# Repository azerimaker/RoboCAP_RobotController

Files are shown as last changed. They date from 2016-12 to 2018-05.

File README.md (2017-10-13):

# RoboCAP Robot Controller
ATmega328 based Robot Remote Controller and Receiver Circuit. [Read more.](http://makerspace-az.org/az/elektronika/robocap-v-1-0-robot-controller/)

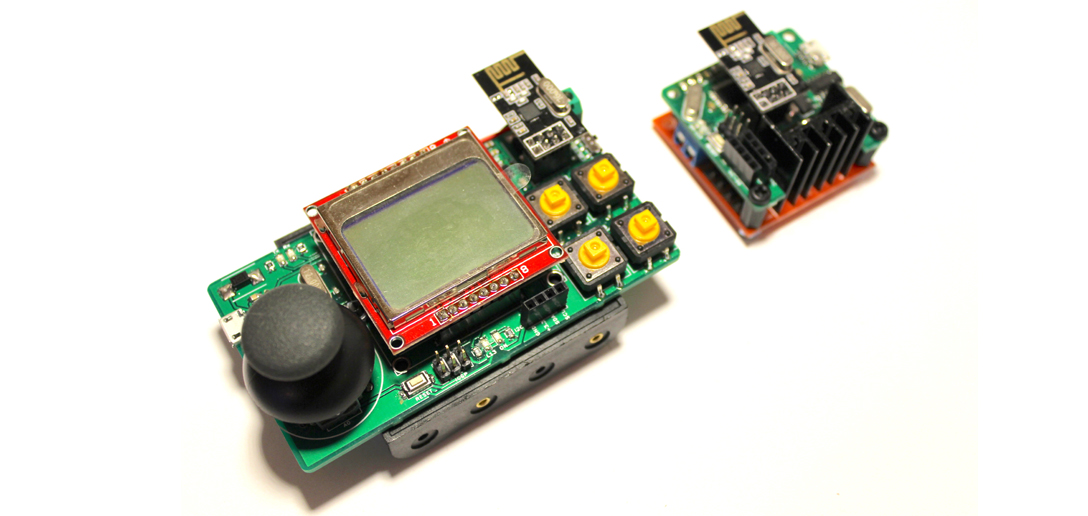
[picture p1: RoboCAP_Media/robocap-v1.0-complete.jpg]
RoboCAP


<div align="center">
<br /> This work is licensed under a <a rel="license" href="http://creativecommons.org/licenses/by-sa/4.0/">Creative Commons Attribution-ShareAlike 4.0 International License</a>.

</div>

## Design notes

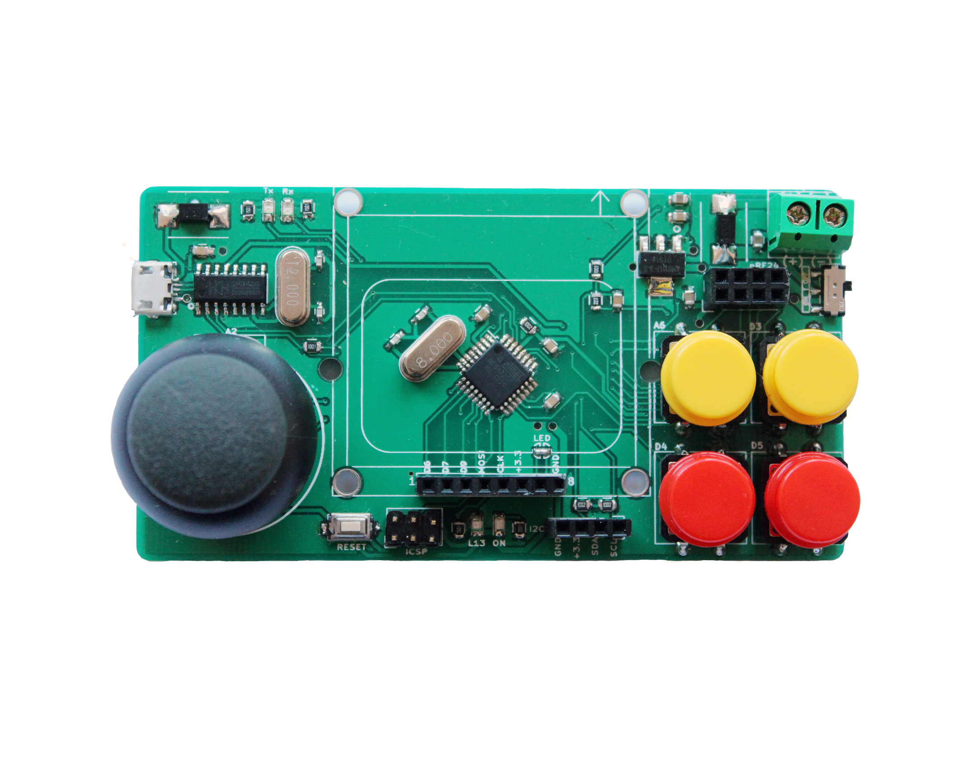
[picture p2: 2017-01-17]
RoboCAP_Media/RoboCAP_Tx.jpg

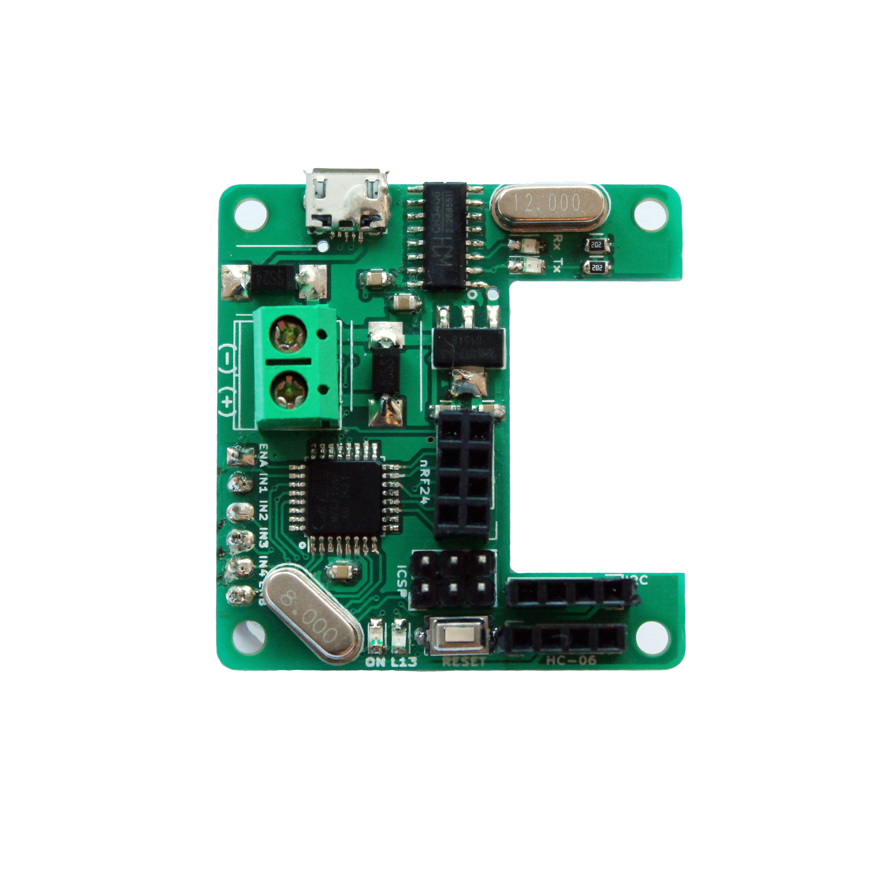
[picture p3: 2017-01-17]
RoboCAP_Media/RoboCAP_Rx.jpg

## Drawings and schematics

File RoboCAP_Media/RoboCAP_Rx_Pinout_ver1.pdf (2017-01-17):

# RoboCAP - Rx ver.1 Pinout

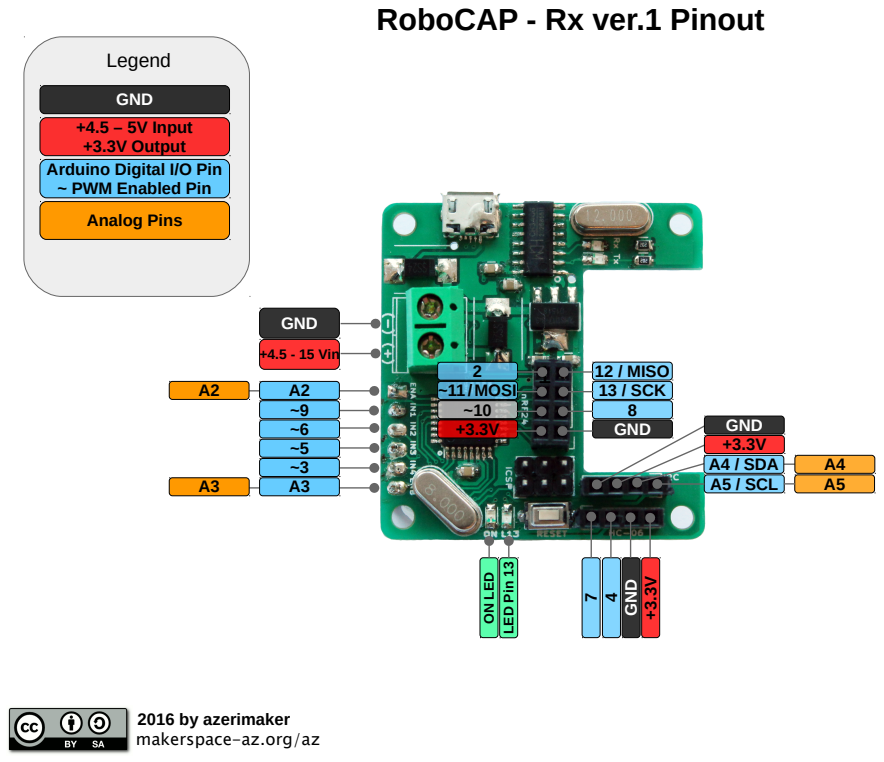
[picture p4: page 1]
~11 /MOSI; 2 12 / MISO; +4.5 - 15 Vin; GND; 8 GND; 13 / SCK; A5 / SCL; A4 / SDA; Legend; Pin

GND
+4.5 – 5V Input
+3.3V Output
Arduino Digital I/O Pin
~ PWM Enabled Pin
Analog Pins

2016 by azerimaker
makerspace-az.org/az

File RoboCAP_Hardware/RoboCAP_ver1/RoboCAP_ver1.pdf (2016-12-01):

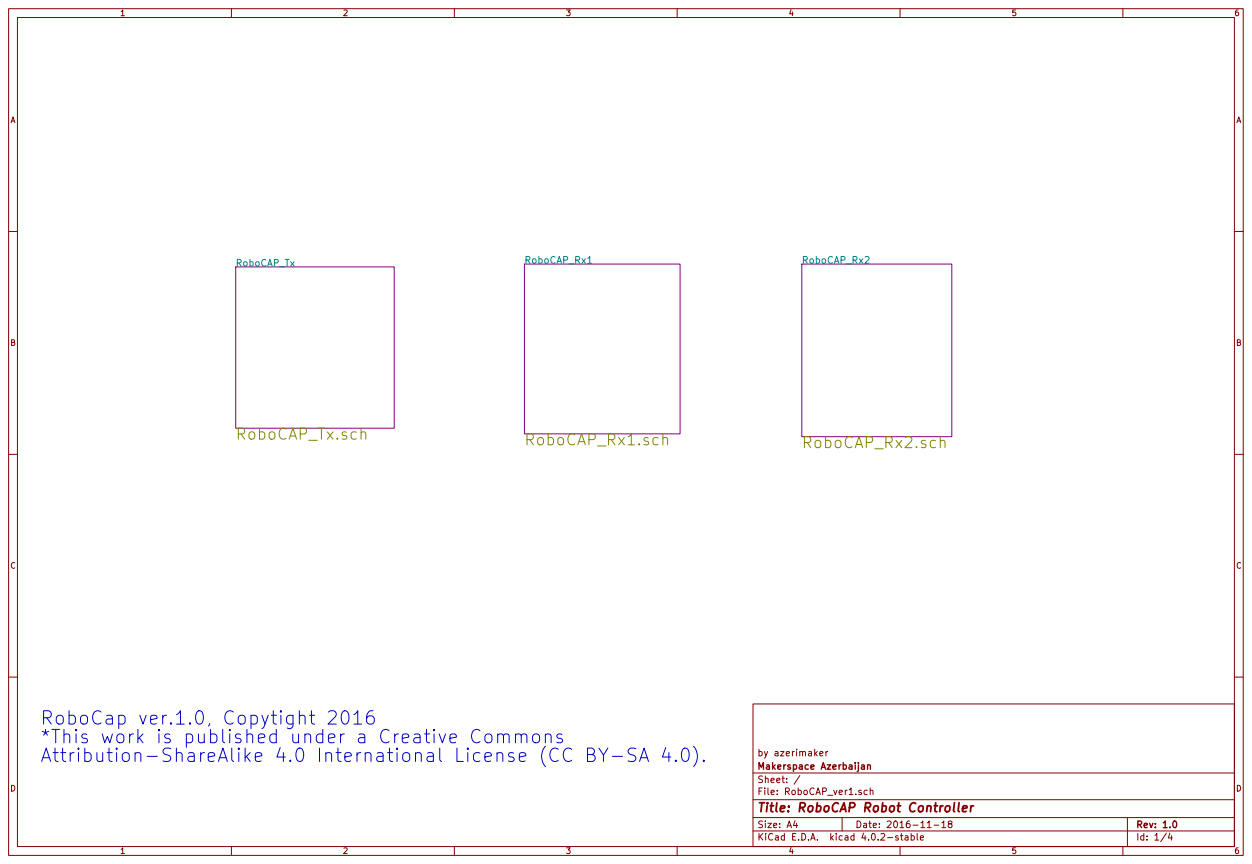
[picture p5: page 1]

RoboCap ver.1.0, Copytight 2016
*This work is published under a Creative Commons
Attribution-ShareAlike 4.0 International License (CC BY-SA 4.0).

by azerimaker
File: RoboCAP_ver1.sch Sheet: / Makerspace Azerbaijan

Id: 1/4 Title: RoboCAP Robot Controller

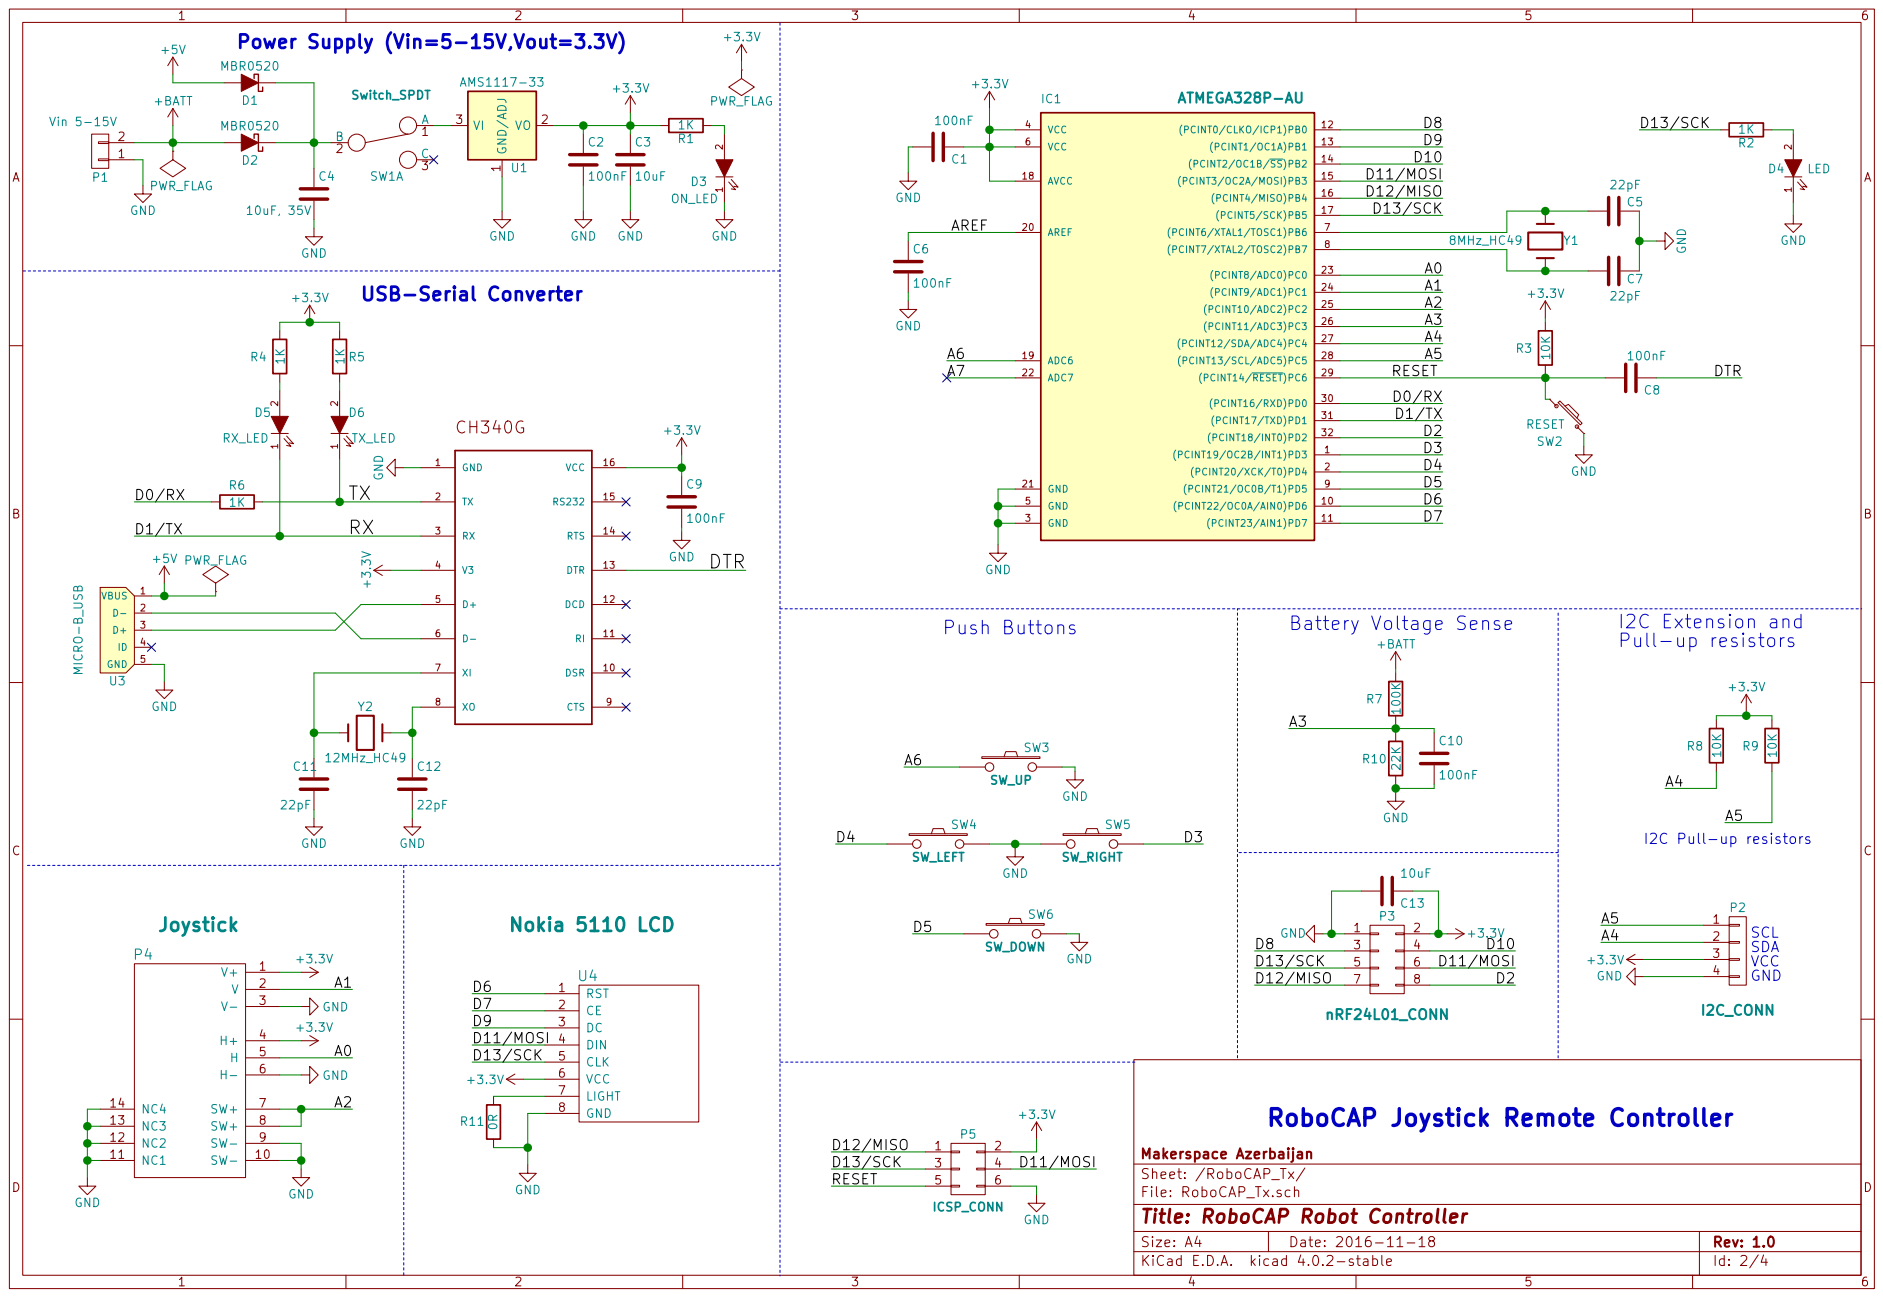
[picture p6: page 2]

RoboCAP Joystick Remote Controller

Makerspace Azerbaijan
Sheet: /RoboCAP_Tx/
File: RoboCAP_Tx.sch
Id: 2/4 Title: RoboCAP Robot Controller

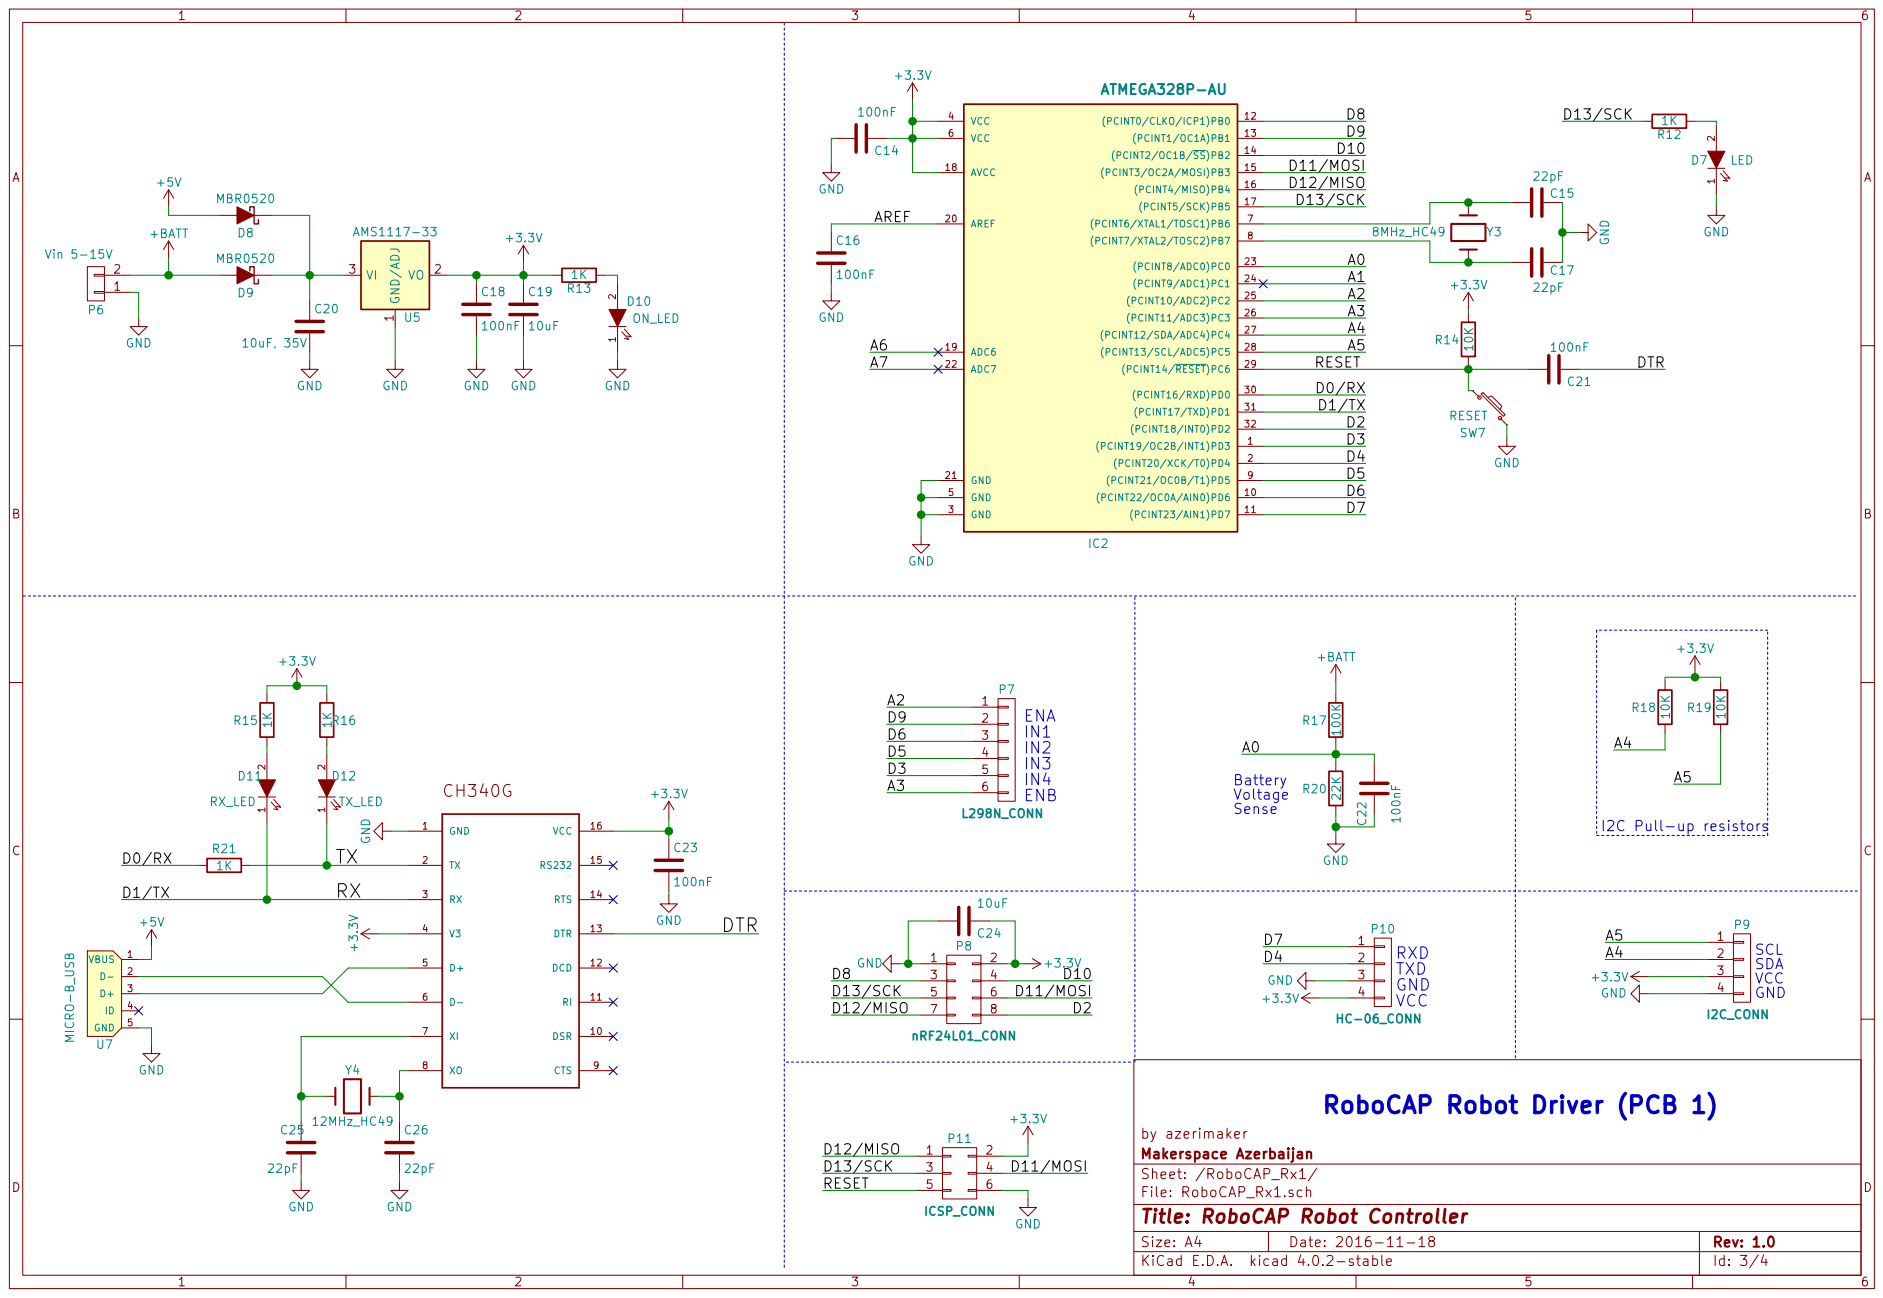
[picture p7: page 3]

RoboCAP Robot Driver (PCB 1)

by azerimaker
Makerspace Azerbaijan
Sheet: /RoboCAP_Rx1/
File: RoboCAP_Rx1.sch
Id: 3/4 Title: RoboCAP Robot Controller

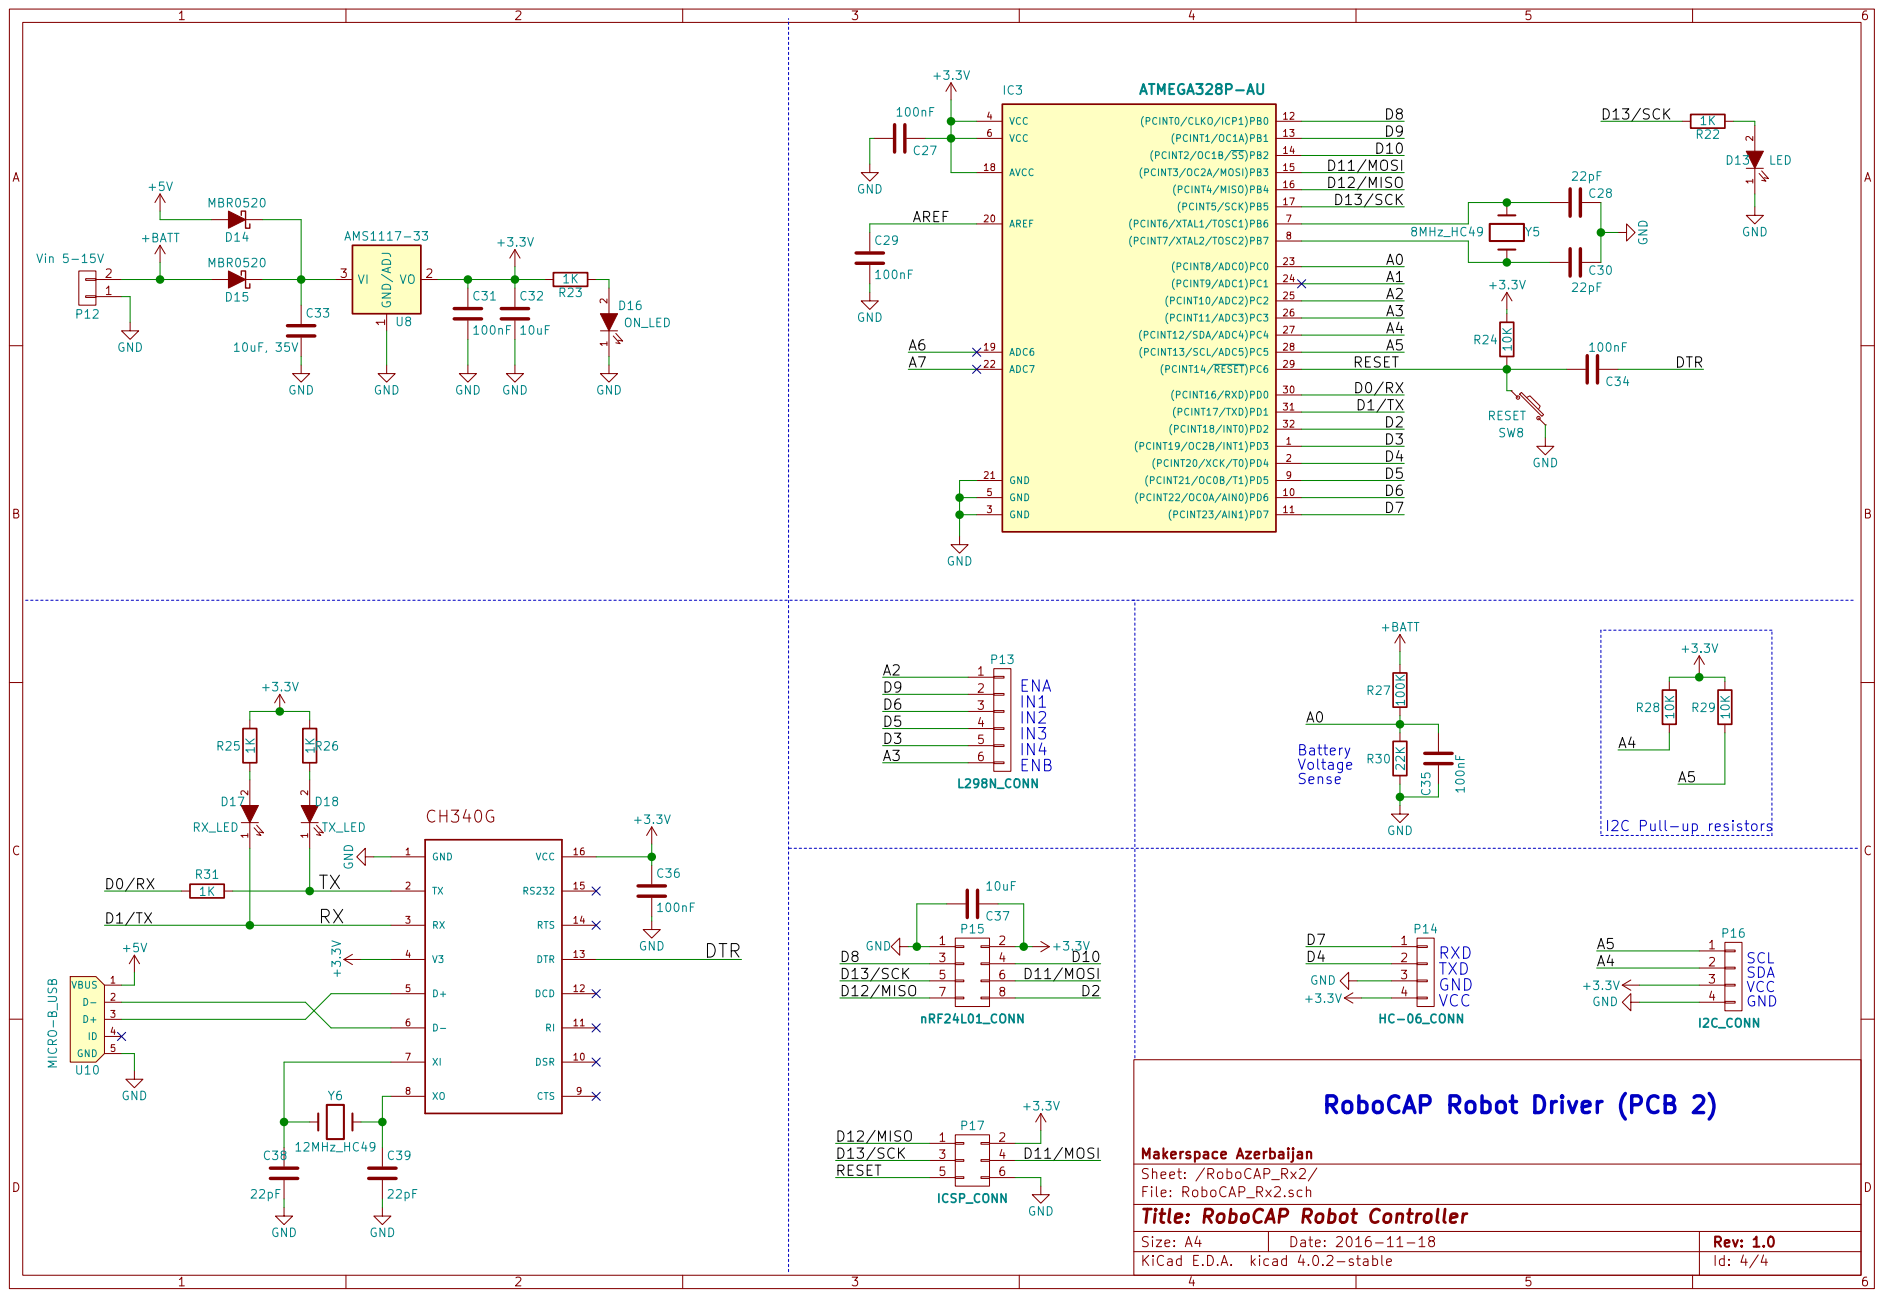
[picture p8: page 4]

RoboCAP Robot Driver (PCB 2)

Makerspace Azerbaijan
Sheet: /RoboCAP_Rx2/
File: RoboCAP_Rx2.sch
Id: 4/4 Title: RoboCAP Robot Controller

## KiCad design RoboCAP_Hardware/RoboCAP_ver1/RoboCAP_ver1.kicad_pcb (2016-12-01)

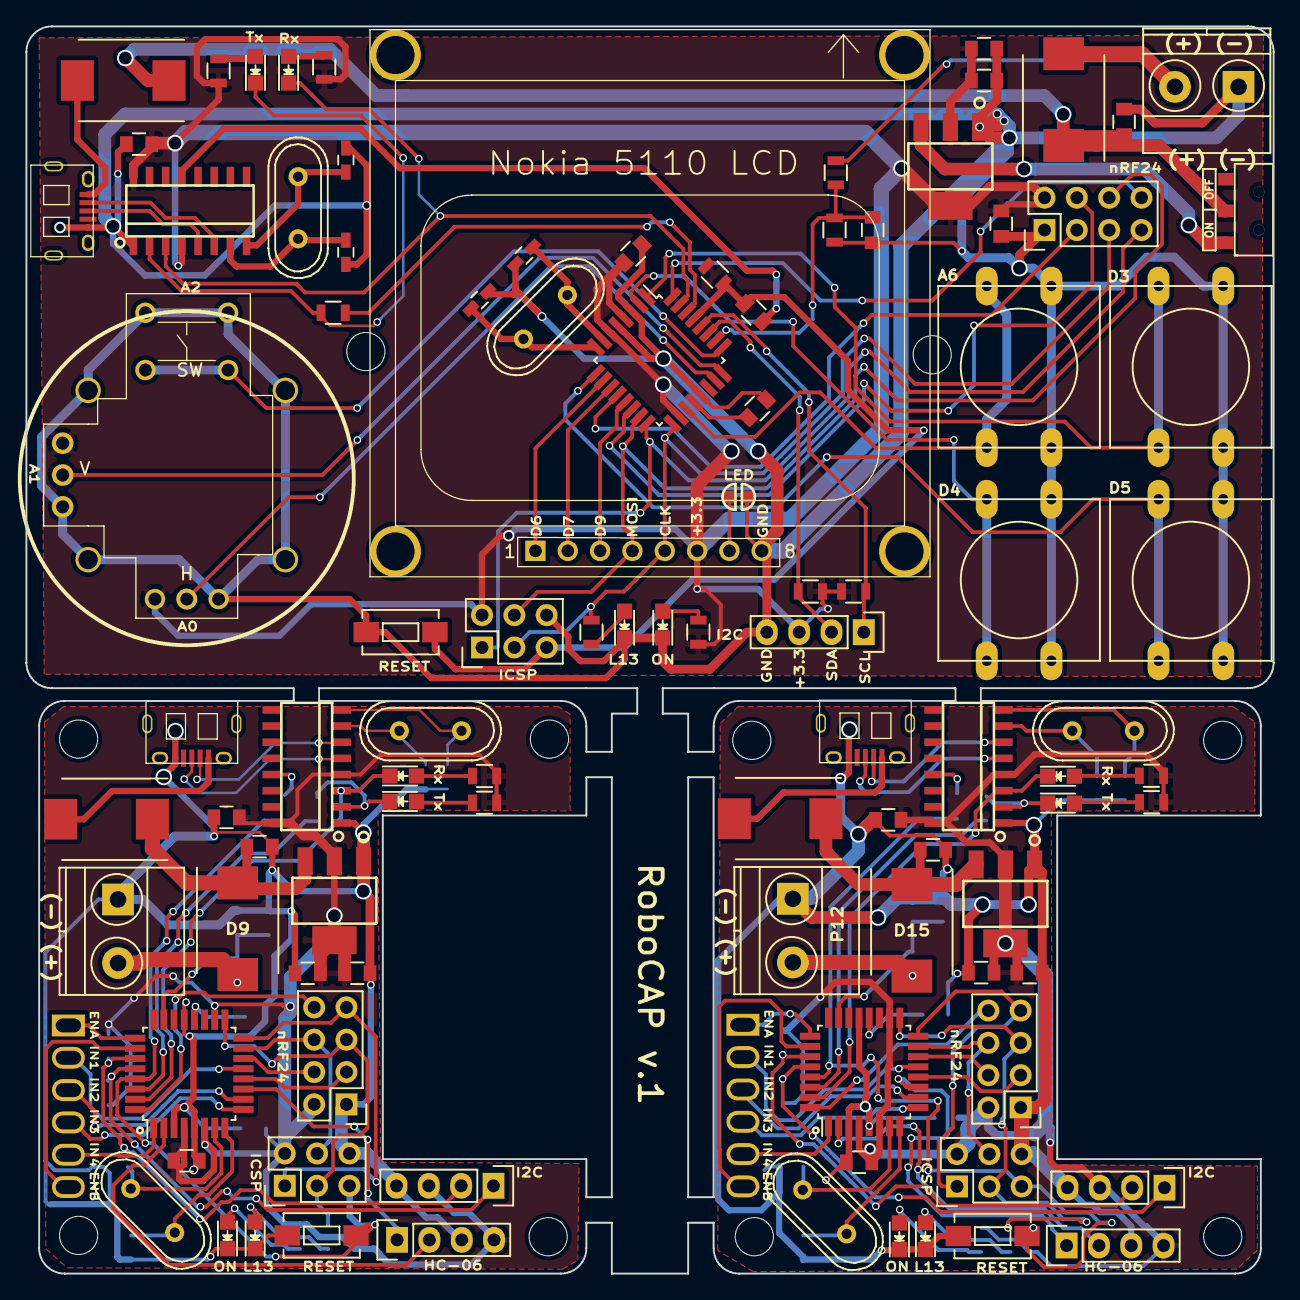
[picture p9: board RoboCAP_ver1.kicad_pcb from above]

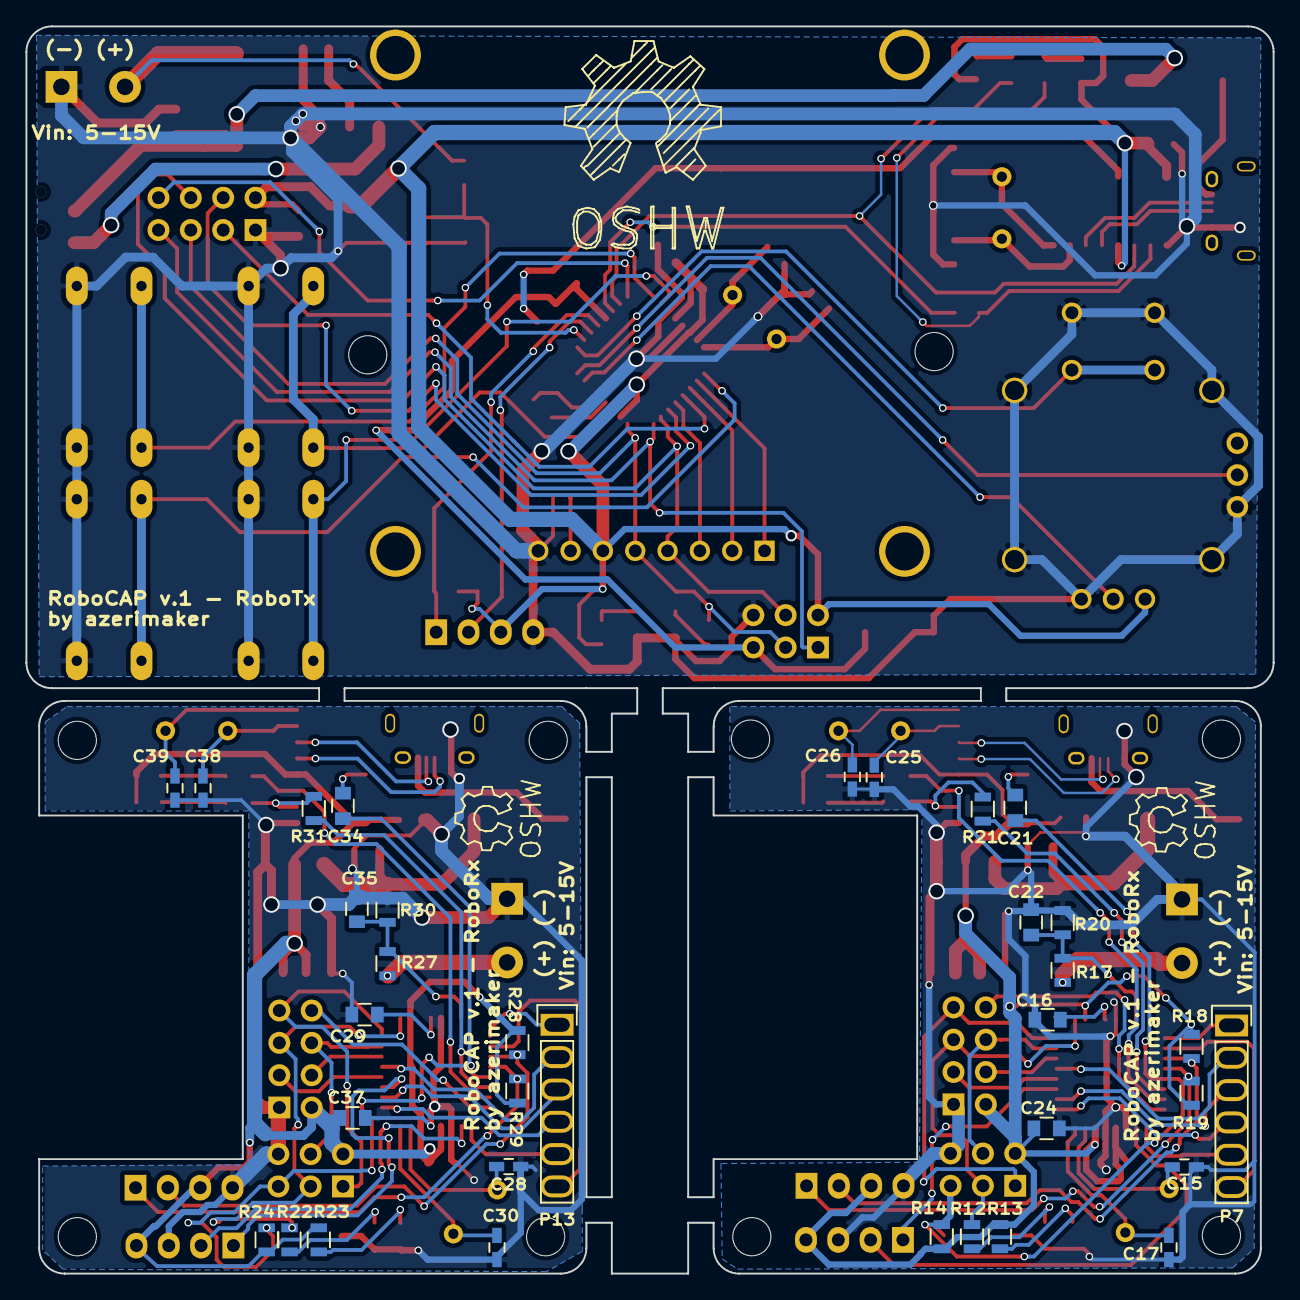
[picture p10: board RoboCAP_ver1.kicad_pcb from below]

Board: 2 copper layers, 98.0 x 98.0 mm, 132 parts (34 on the bottom side), 110 nets.

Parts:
C1, C2, C6, C8, C9, C10, C14, C16, C18, C21, C22, C23, C27, C29, C31, C34, C35, C36: 100nF; C_0805
C3, C13, C19, C24, C32, C37: 10uF; C_0805
C4, C20, C33: 10uF, 35V; C_0805
C5, C7, C11, C12, C15, C17, C25, C26, C28, C30, C38, C39: 22pF; C_0603_HandSoldering
D1, D2, D8, D9, D14, D15: MBR0520; DO-214AB
D3, D10, D16: ON_LED; LED_0805
D4, D7, D13: LED; LED_0805
D5, D11, D17: RX_LED; LED_0805
D6, D12, D18: TX_LED; LED_0805
IC1, IC2, IC3: ATMEGA328P-AU; TQFP-32_7x7mm_Pitch0.8mm
P1, P6, P12: Vin 5-15V; TerminalBlock_Pheonix_MKDS1.5-2pol
P2, P9, P16: I2C_CONN; Pin_Header_Straight_1x04
P3, P8, P15: nRF24L01_CONN; Pin_Header_Straight_2x04
P4: Joystick
P5, P11, P17: ICSP_CONN; Pin_Header_Straight_2x03
P7, P13: L298N_CONN; Pin_Header_Straight_1x06
P10, P14: HC-06_CONN; Pin_Header_Straight_1x04
R1, R2, R4, R5, R6, R12, R13, R15, R16, R21, R22, R23, R25, R26, R31: 1K; R_0805
R3, R8, R9, R14, R18, R19, R24, R28, R29: 10K; R_0805
R7, R17, R27: 100K; R_0805
R10: 33K; R_0805
R11: 0R; SOLDER-JUMPER_1-WAY
R20, R30: 22K; R_0805
SW1: Switch_SPDT; AYZ0102AGRLC
SW2, SW7, SW8: RESET; SW_SPST_EVQPE1
SW3: SW_UP; SW_PUSH-12mm
SW4: SW_LEFT; SW_PUSH-12mm
SW5: SW_RIGHT; SW_PUSH-12mm
SW6: SW_DOWN; SW_PUSH-12mm
U1, U5, U8: AMS1117-33; SOT223
U2, U6, U9: CH340G; SOIC16
U3, U7, U10: MICRO-B_USB; Micro_USB_TH
U4: Nokia 5110 LCD; Nokia_5110_LCD
Y1, Y3, Y5: 8MHz_HC49; Crystal_HC49-U_Vertical
Y2, Y4, Y6: 12MHz_HC49; Crystal_HC49-U_Vertical

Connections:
+3V3: C1.1, C2.1, C3.1, C9.1, C13.1, C14.1, C18.1, C19.1, C23.1, C24.1, C27.1, C31.1, C32.1, C36.1, C37.1, IC1.4, IC1.6, IC1.18, IC2.4, IC2.6, IC2.18, IC3.4, IC3.6, IC3.18, P2.3, P3.2, P4.1, P4.4, P5.2, P8.2, P9.3, P10.4, P11.2, P14.4, P15.2, P16.3, P17.2, R1.2, R3.2, R4.2, R5.2, R8.2, R9.2, R13.2, R14.2, R15.2, R16.2, R18.2, R19.2, R23.2, R24.2, R25.2, R26.2, R28.2, R29.2, U1.2, U1.4, U2.4, U2.16, U4.6, U5.2, U5.4, U6.4, U6.16, U8.2, U8.4, U9.4, U9.16
+5V: D1.2, D8.2, D14.2, U3.1, U7.1, U10.1
+BATT: D2.2, D9.2, D15.2, P1.2, P6.2, P12.2, R7.2, R17.2, R27.2
/RoboCAP_Rx1/A0: C22.2, IC2.23, R17.1, R20.2
/RoboCAP_Rx1/A2: IC2.25, P7.1
/RoboCAP_Rx1/A3: IC2.26, P7.6
/RoboCAP_Rx1/A4: IC2.27, P9.2, R18.1
/RoboCAP_Rx1/A5: IC2.28, P9.1, R19.1
/RoboCAP_Rx1/AREF: C16.1, IC2.20
/RoboCAP_Rx1/D0/RX: IC2.30, R21.1
/RoboCAP_Rx1/D1/TX: D11.1, IC2.31, U6.3
/RoboCAP_Rx1/D2: IC2.32, P8.8
/RoboCAP_Rx1/D3: IC2.1, P7.5
/RoboCAP_Rx1/D4: IC2.2, P10.2
/RoboCAP_Rx1/D5: IC2.9, P7.4
/RoboCAP_Rx1/D6: IC2.10, P7.3
/RoboCAP_Rx1/D7: IC2.11, P10.1
/RoboCAP_Rx1/D8: IC2.12, P8.3
/RoboCAP_Rx1/D9: IC2.13, P7.2
/RoboCAP_Rx1/D10: IC2.14, P8.4
/RoboCAP_Rx1/D11/MOSI: IC2.15, P8.6, P11.4
/RoboCAP_Rx1/D12/MISO: IC2.16, P8.7, P11.1
/RoboCAP_Rx1/D13/SCK: IC2.17, P8.5, P11.3, R12.2
/RoboCAP_Rx1/DTR: C21.1, U6.13
/RoboCAP_Rx1/RESET: C21.2, IC2.29, P11.5, R14.1, SW7.1
/RoboCAP_Rx1/TX: D12.1, R21.2, U6.2
/RoboCAP_Rx2/A0: C35.2, IC3.23, R27.1, R30.2
/RoboCAP_Rx2/A2: IC3.25, P13.1
/RoboCAP_Rx2/A3: IC3.26, P13.6
/RoboCAP_Rx2/A4: IC3.27, P16.2, R28.1
/RoboCAP_Rx2/A5: IC3.28, P16.1, R29.1
/RoboCAP_Rx2/AREF: C29.1, IC3.20
/RoboCAP_Rx2/D0/RX: IC3.30, R31.1
/RoboCAP_Rx2/D1/TX: D17.1, IC3.31, U9.3
/RoboCAP_Rx2/D2: IC3.32, P15.8
/RoboCAP_Rx2/D3: IC3.1, P13.5
/RoboCAP_Rx2/D4: IC3.2, P14.2
/RoboCAP_Rx2/D5: IC3.9, P13.4
/RoboCAP_Rx2/D6: IC3.10, P13.3
/RoboCAP_Rx2/D7: IC3.11, P14.1
/RoboCAP_Rx2/D8: IC3.12, P15.3
/RoboCAP_Rx2/D9: IC3.13, P13.2
/RoboCAP_Rx2/D10: IC3.14, P15.4
/RoboCAP_Rx2/D11/MOSI: IC3.15, P15.6, P17.4
/RoboCAP_Rx2/D12/MISO: IC3.16, P15.7, P17.1
/RoboCAP_Rx2/D13/SCK: IC3.17, P15.5, P17.3, R22.2
/RoboCAP_Rx2/DTR: C34.1, U9.13
/RoboCAP_Rx2/RESET: C34.2, IC3.29, P17.5, R24.1, SW8.1
/RoboCAP_Rx2/TX: D18.1, R31.2, U9.2
/RoboCAP_Tx/A0: IC1.23, P4.5
/RoboCAP_Tx/A1: IC1.24, P4.2
/RoboCAP_Tx/A2: IC1.25, P4.7, P4.8
/RoboCAP_Tx/A3: C10.1, IC1.26, R7.1, R10.2
/RoboCAP_Tx/A4: IC1.27, P2.2, R8.1
/RoboCAP_Tx/A5: IC1.28, P2.1, R9.1
/RoboCAP_Tx/A6: IC1.19, SW3.1
/RoboCAP_Tx/AREF: C6.1, IC1.20
/RoboCAP_Tx/D0/RX: IC1.30, R6.1
/RoboCAP_Tx/D1/TX: D5.1, IC1.31, U2.3
/RoboCAP_Tx/D2: IC1.32, P3.8
/RoboCAP_Tx/D3: IC1.1, SW5.2
/RoboCAP_Tx/D4: IC1.2, SW4.1
/RoboCAP_Tx/D5: IC1.9, SW6.1
/RoboCAP_Tx/D6: IC1.10, U4.1
/RoboCAP_Tx/D7: IC1.11, U4.2
/RoboCAP_Tx/D8: IC1.12, P3.3
/RoboCAP_Tx/D9: IC1.13, U4.3
/RoboCAP_Tx/D10: IC1.14, P3.4
/RoboCAP_Tx/D11/MOSI: IC1.15, P3.6, P5.4, U4.4
/RoboCAP_Tx/D12/MISO: IC1.16, P3.7, P5.1
/RoboCAP_Tx/D13/SCK: IC1.17, P3.5, P5.3, R2.2, U4.5
/RoboCAP_Tx/DTR: C8.1, U2.13
/RoboCAP_Tx/RESET: C8.2, IC1.29, P5.5, R3.1, SW2.1
/RoboCAP_Tx/TX: D6.1, R6.2, U2.2
GND: C1.2, C2.2, C3.2, C4.2, C5.1, C6.2, C7.1, C9.2, C10.2, C11.2, C12.2, C13.2, C14.2, C15.1, C16.2, C17.1, C18.2, C19.2, C20.2, C22.1, C23.2, C24.2, C25.2, C26.2, C27.2, C28.1, C29.2, C30.1, C31.2, C32.2, C33.2, C35.1, C36.2, C37.2, C38.2, C39.2, D3.1, D4.1, D7.1, D10.1, D13.1, D16.1, IC1.3, IC1.5, IC1.21, IC2.3, IC2.5, IC2.21, IC3.3, IC3.5, IC3.21, P1.1, P2.4, P3.1, P4.3, P4.6, P4.9, P4.10, P4.11, P4.12, P4.13, P4.14, P5.6, P6.1, P8.1, P9.4, P10.3, P11.6, P12.1, P14.3, P15.1, P16.4, P17.6, R10.1, R11.2, R20.1, R30.1, SW2.2, SW3.2, SW4.2, SW5.1, SW6.2, SW7.2, SW8.2, U1.1, U2.1, U3.5, U4.8, U5.1, U6.1, U7.5, U8.1, U9.1, U10.5
unnamed: C4.1, D1.1, D2.1, SW1.2
unnamed: C5.2, IC1.7, Y1.1
unnamed: C7.2, IC1.8, Y1.2
unnamed: C11.1, U2.7, Y2.1
unnamed: C12.1, U2.8, Y2.2
unnamed: C15.2, IC2.7, Y3.1
unnamed: C17.2, IC2.8, Y3.2
unnamed: C20.1, D8.1, D9.1, U5.3
unnamed: C25.1, U6.7, Y4.1
unnamed: C26.1, U6.8, Y4.2
unnamed: C28.2, IC3.7, Y5.1
unnamed: C30.2, IC3.8, Y5.2
unnamed: C33.1, D14.1, D15.1, U8.3
unnamed: C38.1, U9.7, Y6.1
unnamed: C39.1, U9.8, Y6.2
unnamed: D3.2, R1.1
unnamed: D4.2, R2.1
unnamed: D5.2, R4.1
unnamed: D6.2, R5.1
unnamed: D7.2, R12.1
unnamed: D10.2, R13.1
unnamed: D11.2, R15.1
unnamed: D12.2, R16.1
unnamed: D13.2, R22.1
unnamed: D16.2, R23.1
unnamed: D17.2, R25.1
unnamed: D18.2, R26.1
unnamed: R11.1, U4.7
unnamed: SW1.1, U1.3
unnamed: U2.5, U3.3
unnamed: U2.6, U3.2
unnamed: U6.5, U7.3
unnamed: U6.6, U7.2
unnamed: U9.6, U10.2
unnamed: U9.5, U10.3

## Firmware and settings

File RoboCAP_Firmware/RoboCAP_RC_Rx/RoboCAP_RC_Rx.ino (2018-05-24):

/*
 * www.Makerspace-Az.org
 * Arduino Sketch: 4X4 Robot masin, Radio Receiver Robot Control (Rx)
 * Kommunikasiya: nRF24L01 2.4GHz
 * son modifikasia tarixi: 21 Iyul 2016
 * [azerimaker]
*/

/*-----( Kitabxana elavesi)-----*/
#include <SPI.h>
#include <RF24.h>
//#include <SoftwareSerial.h>


// eyni anda yalniz bir rejimi aktivlesdirin
//#define BLUETOOTH_MODE
//#define nRF_MODE


/*-----(  Sabitler ve Pin Nomreleri )-----*/
#define MAX_SPEED 255 // analogWrite maks qiymeti

// nRF24L01 modulu uchun
#define CE_PIN   8  
#define CSN_PIN 10

// L298n Motor Surucu pinleri
#define ENA A2      // Motor A Enable 
#define motor1A 9     // INA 
#define motor1B 6     // INB
#define motor2A 5     // INC
#define motor2B 3     // IND
#define ENB A3		  // Motor B Enable

#define VBAT A0      // Batareya gerginliyi
#define V_Divider_Coeff 0.01801F // gerginlik bolucuden alinir

// HC-06 Bluetooth Modul pinleri
//#define Rx 4          // -> HC-06 TxD    
//#define Tx 7 		  // -> HC-06 RxD

#define X_min 480
#define X_max 530
#define Y_min 480
#define Y_max 530

 // deyishenlar ve sabitler
//char BT_RECEIVED;   // BT-dan gelen simvol
//char PC_RECEIVED;   // PC-den gelen simvol

/*-----( Radio Obyektinin yaradilmasi )-----*/
RF24 radio(CE_PIN, CSN_PIN);
// Hardware serial PC ile kommunikasiya ucun lazim oldughu ucun SoftwareSerial ishledirik
//SoftwareSerial BTserial(Rx, Tx);

/*-----( Funksiya Prototipleri )-----*/
void calcDirection(int X_pos, int Y_pos);
void calcSpeed(int X_pos, int Y_pos);
void driveRobot(char DIRECTION, unsigned char SPEED);
void setSpeedRight(unsigned char SPEED, boolean DIR);
void setSpeedLeft(unsigned char SPEED, boolean DIR);
void motorTormozla(void);
int  readBatteryVoltage(void);

/*-----( Deyishenler )-----*/
byte addresses[][6] = {"1Node", "2Node"}; //  nRF ucun "Pipe" adlari
byte failsafe_count = 0; 

struct dataStruct {
  unsigned long micro_sec;  // to save response times
  int Xposition;          // The Joystick position values
  int Yposition;
  bool switchOn;          // The Joystick push-down switch
  bool TL_BTN; 
  bool TR_BTN;
  bool BL_BTN;
  bool BR_BTN;
  int robot_Vbat;
} myData;  

char Joystick_Dir;     // Joystick kordinatlarini hereket istiqametine ve 
unsigned char Joystick_Speed = 0;   // surete cevirmek
int X_map, Y_map;
unsigned int X_sq, Y_sq;     // suret vektorunun hesablamaq uchun

boolean FORWARD = true; // ireli
boolean BACKWARD = false; // geri

/****** SETUP: Bir defe icra olunacaq ******/                       
void setup() 
{
  Serial.begin(9600);
  
  pinMode(motor1A, OUTPUT);
  pinMode(motor1B, OUTPUT);
  pinMode(motor2A, OUTPUT);
  pinMode(motor2B, OUTPUT);
  pinMode(ENA, OUTPUT);
  pinMode(ENB, OUTPUT);
  
  // L298n aktivlesdir 
  digitalWrite(ENA, HIGH);
  digitalWrite(ENB, HIGH);
  motorTormozla(); // tekerleri tormozla, ehtiyat ucun
  
  //BTserial.begin(9600);
  radio.begin();  
  radio.setChannel(108);  //   2.508 Ghz - WiFi siqnallarindan yuksek bir kanal deyeri sech
  radio.setDataRate(RF24_250KBPS); // Data gonderme sureti
  radio.setPALevel(RF24_PA_LOW); // Oturme gucu: RF24_PA_MIN, RF24_PA_LOW, RF24_PA_HIGH, RF24_PA_MAX

  radio.openWritingPipe(addresses[1]); // Oturucu Pipe (kanali) ishe sal
  radio.openReadingPipe(1, addresses[0]); // Qebul Pipe (kanali) ishe sal
  
  radio.startListening(); // Radio siqnallari dinlemeye bashla
  //radio.printDetails(); //kommenti sileniz coxlu Debug informasiyasi print olunacaq

} /****** SETUP sonu ******/


// implement MODE selection

 /****** LOOP: Daimi tekrarlanir ******/
void loop()
{ 
    if ( radio.available() )
    {		
      while ( radio.available() )   // Qebul Pipe-da melumat olarsa
      {
        radio.read( &myData, sizeof(myData) ); // Radio melumati oxu
      }
      
      radio.stopListening();  
        myData.robot_Vbat =  readBatteryVoltage();           // Batareya gerginliyini elave et                        // First, stop listening so we can transmit
        radio.write( &myData, sizeof(myData) );              // Send the received data back.
      radio.startListening();                              // Now, resume listening so we catch the next packets.
      

      // Yeni qebul olunmush melumati robotun hereket sxemine uyghunlashdir
      calcDirection(myData.Xposition, myData.Yposition); // S,F,B,L,R,I,G,H,J
      calcSpeed(myData.Xposition, myData.Yposition);  // 0-255
      driveRobot(Joystick_Dir, Joystick_Speed);

      Serial.print("X:"); Serial.print(myData.Xposition);
      Serial.print(" Y:"); Serial.print(myData.Yposition);
      Serial.print(" SW:"); Serial.print(myData.switchOn);
      Serial.print(" A6:"); Serial.print(myData.TL_BTN); 
      Serial.print(" D3:"); Serial.print(myData.TR_BTN);
      Serial.print(" D4:"); Serial.print(myData.BL_BTN);
      Serial.print(" D5:"); Serial.print(myData.BR_BTN);
      Serial.print(" vBat:"); Serial.print(myData.robot_Vbat);
      Serial.print(" Dir:"); Serial.print(Joystick_Dir);
      Serial.print(" Speed:"); Serial.println(Joystick_Speed);

    }else{
      failsafe_count++; 
      if(failsafe_count>10){
        failsafe_count=0;
        motorTormozla();
      }
    }
    delay(20);

}  /****** LOOP sonu ******/

 /*
 * Bu funksiya X,Y qiymetlerine esasen qlobal 
 * Istiqamet deyishenini yenileyir 
 */ 

 void calcDirection(int X_pos, int Y_pos){
  
  if((X_pos >= X_min && X_pos <= X_max) && Y_pos >= Y_max)
  {
    Joystick_Dir = 'F';
  }
  else if(X_pos >= X_min && X_pos <= X_max && Y_pos <= Y_min)
  {
    Joystick_Dir = 'B';
  }
  else if(Y_pos >= Y_min && Y_pos <= Y_max && X_pos >= X_max)
  {
    Joystick_Dir = 'L';
  }
  else if(Y_pos >= Y_min && Y_pos <= Y_max && X_pos <= X_min)
  {
    Joystick_Dir = 'R';
  }
  else if(X_pos <= X_min && Y_pos >= Y_max)
  {
    Joystick_Dir = 'I';
  }
  else if(X_pos >= X_max && Y_pos >= Y_max)
  {
    Joystick_Dir = 'G';
  }
  else if(X_pos >= X_max && Y_pos <= Y_min)
  {
    Joystick_Dir = 'H';
  }
  else if(X_pos <= X_min && Y_pos <= Y_min)
  {
    Joystick_Dir = 'J';
  }
  else{
      Joystick_Dir = 'S'; // deadzone
  }
}



/*
 * Bu funksiya X,Y qiymetlerine esasen qlobal 
 * Suret deyishenini yenileyir 
 */ 

 void calcSpeed(int X_pos, int Y_pos){

  X_map = map(X_pos, 0, 1023, -255, 255); // intervali deyish
  Y_map = map(Y_pos, 0, 1023, -255, 255);
  
  X_map = abs(X_map); // musbet edede cevir
  Y_map = abs(Y_map);

  X_sq = sq(X_map); // kvadrata yukselt
  Y_sq = sq(Y_map);

  Joystick_Speed = (unsigned char)sqrt(X_sq + Y_sq); // Joystick suret vektorunu hesabla, Pifaqor teoremi :)
  if(Joystick_Speed>255){
    Joystick_Speed = 255;
  }
}

/*
 * Bu funksiya suret ve istiqamet deyishenine esasen motor suretini
 * teyin edir 
 */ 


void driveRobot(char DIRECTION, unsigned char SPEED)
{ 
  
  byte speed = map(SPEED, 0, MAX_SPEED, 0, 255);// SPEED 0-100, intervali deyish 0-255
  byte speed_div2 = speed/2;
  byte speed_div4 = speed/4;
  
  switch(DIRECTION){
      case 'F': // Forward - Ireli
          setSpeedRight(speed, FORWARD);
          setSpeedLeft( speed, FORWARD);
          break;
      case 'B': // Backward - Geri
          setSpeedRight(speed, BACKWARD);
          setSpeedLeft( speed, BACKWARD);
          break;
      case 'L': // Left - Sola
          setSpeedRight(speed_div4, FORWARD);
          setSpeedLeft( speed_div4, BACKWARD);
          break;
      case 'R': // Right - Sagha
          setSpeedRight(speed_div4, BACKWARD);
          setSpeedLeft( speed_div4, FORWARD);
          break;
      case 'G': // Left + Forward
          setSpeedRight(speed, FORWARD);
          setSpeedLeft( speed_div2, FORWARD);
            break;
      case 'I': // Right + Forward
          setSpeedRight(speed_div2, FORWARD);
          setSpeedLeft( speed, FORWARD);
          break;
      case 'H': // Left + Backward
          setSpeedRight(speed, BACKWARD);
          setSpeedLeft( speed_div2, BACKWARD);
          break;  
      case 'J': // Right + Backward 
          setSpeedRight(speed_div2, BACKWARD);
          setSpeedLeft( speed, BACKWARD);
          break; 
      default: 
            motorTormozla(); // istenilen bashqa simvol olduqda tekerleri tormozla
            break;
    }
}


/*
 * sag ve sol tekerlerin suretini ve istiqametini 
 * teyin eden funksiyalar
 */ 
 
void setSpeedRight(unsigned char SPEED, boolean DIR)
{
  if(DIR == true){
      digitalWrite(motor2A, LOW);
      analogWrite (motor2B, SPEED);
  }
  else{
      analogWrite(motor2A, SPEED);
      digitalWrite(motor2B, LOW);
  }
  
}

void setSpeedLeft(byte SPEED, boolean DIR)
{
  if(DIR == true){
      analogWrite(motor1A, SPEED);
      digitalWrite(motor1B, LOW);  
  }
  else{
       
      digitalWrite(motor1A, LOW);
      analogWrite (motor1B, SPEED);
  }
  
}

void motorTormozla(void)
{
    digitalWrite(motor1A, LOW);
    digitalWrite(motor1B, LOW);
    digitalWrite(motor2A, LOW);
    digitalWrite(motor2B, LOW);
}


int  readBatteryVoltage(void){
  int voltage = 1000 * V_Divider_Coeff * analogRead(VBAT); // convert raw analog to mV
  //TODO: convert raw ADC reading to mV 
  return voltage; // milliVolt
}

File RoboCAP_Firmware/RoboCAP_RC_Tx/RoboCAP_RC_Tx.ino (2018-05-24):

/*
 * www.Makerspace-Az.org
 * Arduino Sketch: 4X4 Robot masin, Radio Transmitter (Tx)
 * Kommunikasiya: nRF24L01 2.4GHz
 * son modifikasia tarixi: 16 May 2016
 * [azerimaker]
*/

/*-----( Kitabxana elavesi)-----*/
#include <SPI.h>
#include <RF24.h>
/*-----(  Sabitler ve Pin Nomreleri )-----*/
#define CE_PIN   8
#define CSN_PIN 10
// Joystick
#define JOYSTICK_X   A0  // Joystick VRx Analoq pin A0-a baglanir
#define JOYSTICK_Y   A1  // Joystick VRy Analoq pin A1-e baglanir
#define JOYSTICK_SW  A2  //  Joystick merkeze basildiqda achar
// Buttons
#define TOP_LEFT_BTN A6
#define TOP_RIGT_BTN 3
#define BOTTOM_LEFT_BTN 4
#define BOTTOM_RIGHT_BTN 5

#define VBAT_SENSE A3

// Nokia LCD



/*-----( Radio Obyektinin yaradilmasi )-----*/
RF24 radio(CE_PIN, CSN_PIN); 

/*-----( Deyishenler )-----*/
byte addresses[][6] = {"1Node", "2Node"}; //  "Pipe" adi, nrf24l01 uchun

unsigned long timeNow;  // Used to grab the current time, calculate delays
unsigned long started_waiting_at;
boolean timeout;       // Timeout? True or False

// Proqramla Analoq qiymetleri filterleme uchun deyishenler
int X_qiymeti = 0;
int Y_qiymeti = 0;        
float X_exp_emsal = 1;      // exponensial emsal qiymeti, 1-olduqda filtirleme deaktiv olur
float Y_exp_emsal = 1;      // bu emsali isteyinize gore deyishe bilersiniz (0-1] aralighinda
int X_exp_cem = 0;            // exponensial cemin bashlangic qiymeti
int Y_exp_cem = 0;     

// Joystick qiymetleri olan deyishenler strukturu

struct dataStruct {
  unsigned long micro_sec;  // to save response times
  int Xposition;          // The Joystick position values
  int Yposition;
  bool switchOn;          // The Joystick push-down switch
  bool TL_BTN; 
  bool TR_BTN;
  bool BL_BTN;
  bool BR_BTN;
  int robot_Vbat;
} myData;                 


 /****** SETUP: Bir defe icra olunacaq ******/
void setup()  
{
  Serial.begin(9600);
  		 								//  daxili Pull-up rezistorunu ishe saliriq
  pinMode(JOYSTICK_SW, INPUT_PULLUP);  // Kenar rezistor ishletmeye ehtiyac yoxdu                             
  pinMode(TOP_LEFT_BTN, INPUT); // Analog pin oldughu ucun PULLUP yoxdur
  pinMode(TOP_RIGT_BTN, INPUT_PULLUP);
  pinMode(BOTTOM_LEFT_BTN, INPUT_PULLUP);
  pinMode(BOTTOM_RIGHT_BTN, INPUT_PULLUP);            

  radio.begin();          // nRF24L01 Radio transiveri ishe sal
  radio.setChannel(108);  //  WiFi siqnallarindan yuksek bir kanal deyeri sech
  radio.setDataRate(RF24_250KBPS); // Data gonderme sureti
  radio.setPALevel(RF24_PA_HIGH); // Oturme gucu: RF24_PA_MIN, RF24_PA_LOW, RF24_PA_HIGH, RF24_PA_MAX
 
  radio.openWritingPipe(addresses[0]); // Gonderme Pipe (kanali) ishe sal
  radio.openReadingPipe(1, addresses[1]);
  radio.startListening();
//  radio.printDetails(); //kommenti sileniz coxlu Debug informasiyasi print olunacaq

  // Filterleme ucun bashlangic hesablama
  X_exp_cem =  analogRead(JOYSTICK_X); 
  Y_exp_cem =  analogRead(JOYSTICK_Y); 
  
} /****** SETUP sonu ******/


 /****** LOOP: Daimi tekrarlanir ******/
void loop()  
{
  radio.stopListening();  

  /*********************( Read Controller Buttons and Joystick )***********************/
  X_qiymeti = analogRead(JOYSTICK_X);
  Y_qiymeti = analogRead(JOYSTICK_Y);

  myData.Xposition = X_qiymeti; // Filter olunmamish qiymetler
  myData.Yposition = Y_qiymeti;

  myData.switchOn  = !digitalRead(JOYSTICK_SW);  // Achar basildiqda 0V oldughu ucun, inversiya etmeliyik

  int A6_value = analogRead(TOP_LEFT_BTN); // A6 Analog IN only
  if(A6_value >0){myData.TL_BTN = 0;}
  else{myData.TL_BTN = 1;}

  myData.TR_BTN = !digitalRead(TOP_RIGT_BTN);
  myData.BL_BTN = !digitalRead(BOTTOM_LEFT_BTN);
  myData.BR_BTN = !digitalRead(BOTTOM_RIGHT_BTN);
  myData.micro_sec = micros();  // Send back for timing


/* 
 * Bu emeliyyat zamani X_exp_emsal qiymeti ne qeder kicik olarsa, 
 * yeni oxunan X_qiymeti yekun X_exp_cem qiymetine bir o qeder az 
 * tesir edecek, neticede sert kecidler, yumshaq olacaq
 * 
 */


//  X_exp_cem = (X_exp_emsal * X_qiymeti) + ((1-X_exp_emsal)*X_exp_cem); // Exponensial filterleme emeliyyati
//  Y_exp_cem = (Y_exp_emsal * Y_qiymeti) + ((1-Y_exp_emsal)*Y_exp_cem); 
        
//  myData.Xposition = X_exp_cem; // Filter olunmush qiymetleri umumi struktura yaz
//  myData.Yposition = Y_exp_cem;

  // Bu Serial Print-leri komment ede bilersiniz. 
  Serial.print("Indi gonderilir, X= ");
  Serial.print(myData.Xposition);
  Serial.print(", Y= ");
  Serial.print(myData.Yposition);
  if ( myData.switchOn == 1)
  {
      Serial.println(", ON");
  }else
  {
      Serial.println(", OFF");
  }

  if(!radio.write( &myData, sizeof(myData) )) {  // Melumati gonder ve xeta olarsa print
     Serial.println("Gonderilme ugursuz oldu");
  }

  radio.startListening();                      // Now, continue listening
  started_waiting_at = micros();               // timeout period, get the current microseconds
  timeout = false;                            //  variable to indicate if a response was received or not

  while ( !radio.available() ){                            // While nothing is received
    if (micros() - started_waiting_at > 200000 ){           // If waited longer than 200ms, indicate timeout and exit while loop
      timeout = true;
      break;
      }
  }

  if ( timeout ){ // Describe the results
    Serial.println(F("Response timed out -  no Acknowledge.")); // passing flash-memory based strings to save SRAM
  }else
  {
    // Grab the response, compare, and send to Serial Monitor
    radio.read( &myData, sizeof(myData) );
    timeNow = micros();
/*
    Serial.print(F("Sent "));
    Serial.print(timeNow);
    Serial.print(F(", Got response "));
    Serial.print(myData.micro_sec);
    Serial.print(F(", Round-trip delay "));
    Serial.print(timeNow - myData.micro_sec);
    Serial.println(F(" microseconds "));
*/
  }
  
  delay(10); // Delay olmasi stabilliyi artirir. 
  

} /****** LOOP sonu ******/

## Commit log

2016-12-01 RoboCAP firmware and board files added
    [RoboCAP_Rx1.sch, RoboCAP_Rx2.sch, RoboCAP_Tx.sch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]
2018-05-24 RoboCap-Driver-improvements
    added failsafe
